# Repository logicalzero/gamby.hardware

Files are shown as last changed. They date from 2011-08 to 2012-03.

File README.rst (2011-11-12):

gamby.hardware README
=====================

This repository contains the EAGLE files for the GAMBY LCD/Game shield for
Arduino.

If anyone is interested in porting the design over to a non-proprietary
format (e.g. gEDA), please contact me! 

Design Notes
------------

* Every Arduino pin has a second pad. These pads conform to a uniform .1" spacing, correcting the .05" offset of the header for digital I/O pins 8-13 and GND/AREF.

* Although it uses the same pins, this design does not use the ATMega's built-in SPI. Since this device does not support bidirectional communication, using the built-in SPI would have wasted a pin; it would have overly complicated the traces as well.

* The traces between all of the 'used' Arduino pins and the second pad have been left uncovered by the bottom soldermask. This is to make it easier to cut the traces should the user want to rewire things -- to make use of the hardware SPI, for example.

* The sound, D-Pad and buttons have pads for headers; the pads are shorted by a thin, uncovered trace. The sound and inputs can be disabled by cutting this trace, then re-enabled by adding a 2-pin header (3 pins, in the case of sound) and a jumper.

Prototypes
----------

The items in the prototypes directory are the versions that were sent for 
short-run fabrication. The pin-out of the first prototype differs from
the new version. The second prototype has a few minor adjustments made
to make it compatible with the fabrication service (0.1" milling bit,
etc.). 

Datasheets
----------

* LCD: Samsung UG09B63-FLGT4AA using `S6B0755 LCD Controller <http://www.alldatasheet.com/datasheet-pdf/pdf/37866/SAMSUNG/S6B0755.html>`__ or compatible (some features unsupported)
* D-Pad: `ALPS SKQAAA010 4-direction switch <http://www.alldatasheet.com/datasheet-pdf/pdf/329112/ALPS/SKQU.html>`__
* Piezo speaker: `TDK PS1240P02BT <http://www.alldatasheet.com/datasheet-pdf/pdf/349367/TDK/PS1720P02.html>`__
* Backlight LEDs: `Dialight 598-8340-107F <http://www.dialight.com/Assets%5CBrochures_And_Catalogs%5CIndication%5CMDEI5981208RT.pdf>`__

Thanks
------

Thanks go out to my fellow Boston dorkbotter, Tim, for reverse engineering
the surplus LCD module.

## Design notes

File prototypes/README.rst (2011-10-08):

prototypes
==========

About
-----

This directory contains the EAGLE source files used to manufacture the GAMBY 
prototype boards. These are here for reference only; the final designs 
improve upon there.

Pin Changes
-----------

Several pins were changed between Prototype 1 and Prototype 2. The new pinout
is expected to be the final version. The GAMBY libraries will be written to use
the new pins; if you are one of the few with a Prototype 1 board you will need
to modify the code or the board itself.

+---------------+-------+-------+
|   Function    |  old  |  new  |
+===============+=======+=======+
| LCD SID       |    8  |    8  |
+---------------+-------+-------+
| LCD SCK       |    9  |   10  |
+---------------+-------+-------+
| LCD RS        |   10  |   11  |
+---------------+-------+-------+
| LCD RESET     |   11  |   12  |
+---------------+-------+-------+
| LCD CS        |   12  |   13  |
+---------------+-------+-------+
+---------------+-------+-------+
| B1/Up         |    7  |    7  |
+---------------+-------+-------+
| B2/Left       |    5  |    6  |
+---------------+-------+-------+
| B3/Right      |    4  |    5  |
+---------------+-------+-------+
| B4/Down       |    2  |    4  |
+---------------+-------+-------+
+---------------+-------+-------+
| Audio         |    3  |    9  |
+---------------+-------+-------+

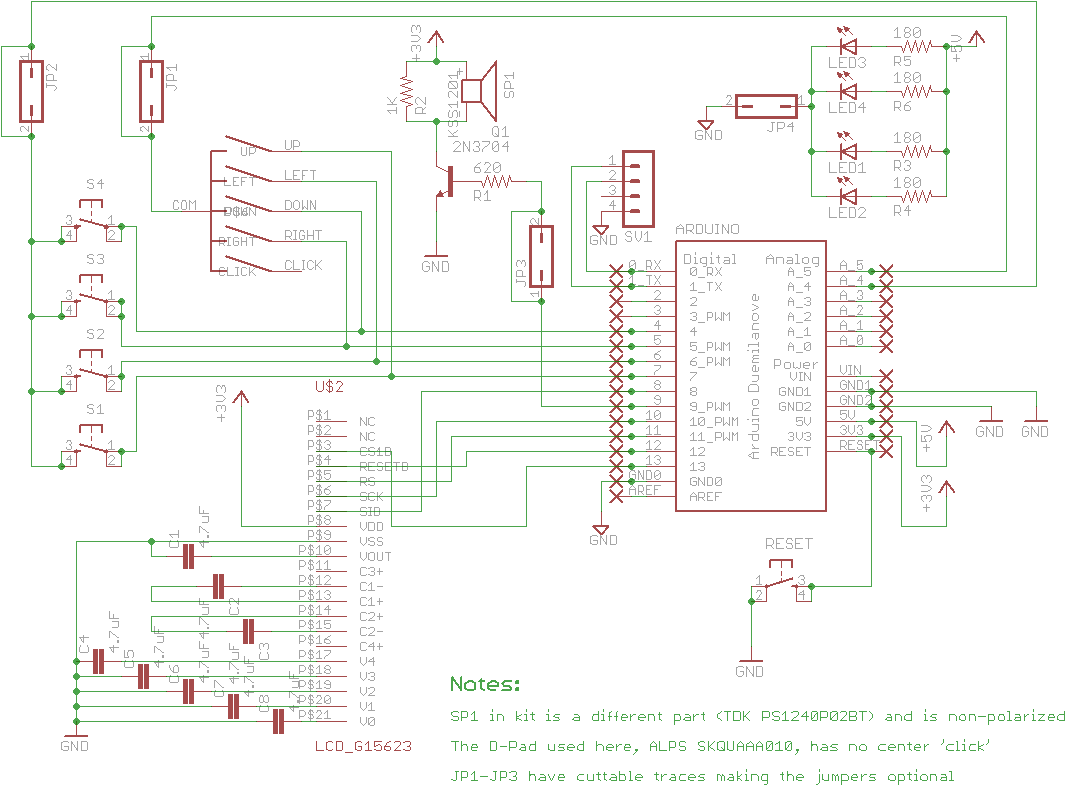
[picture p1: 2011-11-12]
schematic.png

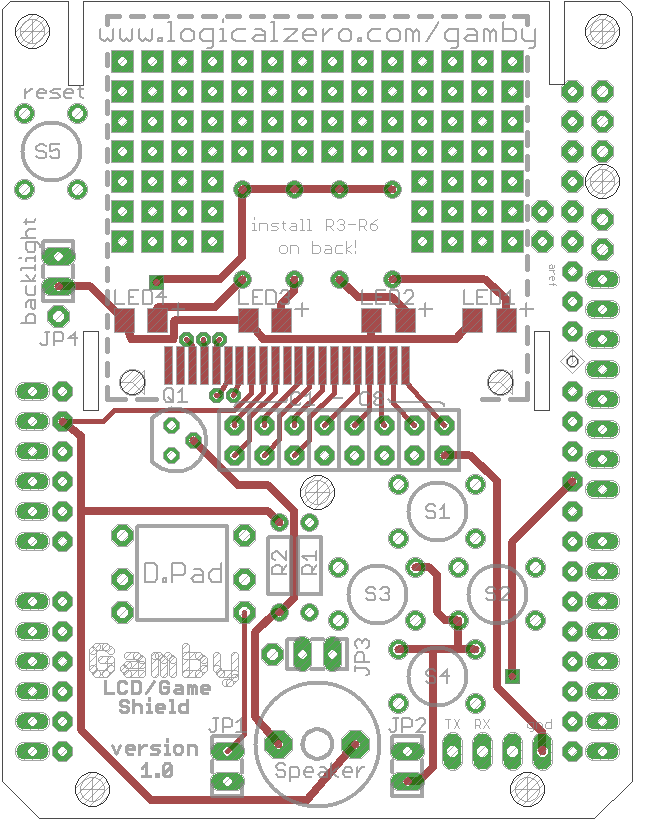
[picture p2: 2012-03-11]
board_top.png

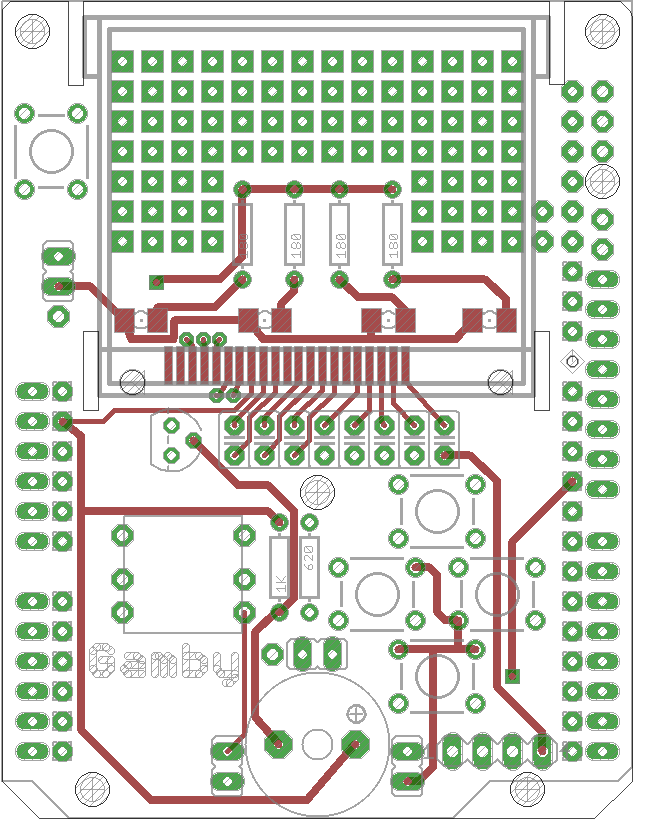
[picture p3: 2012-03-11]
board_top_placement.png

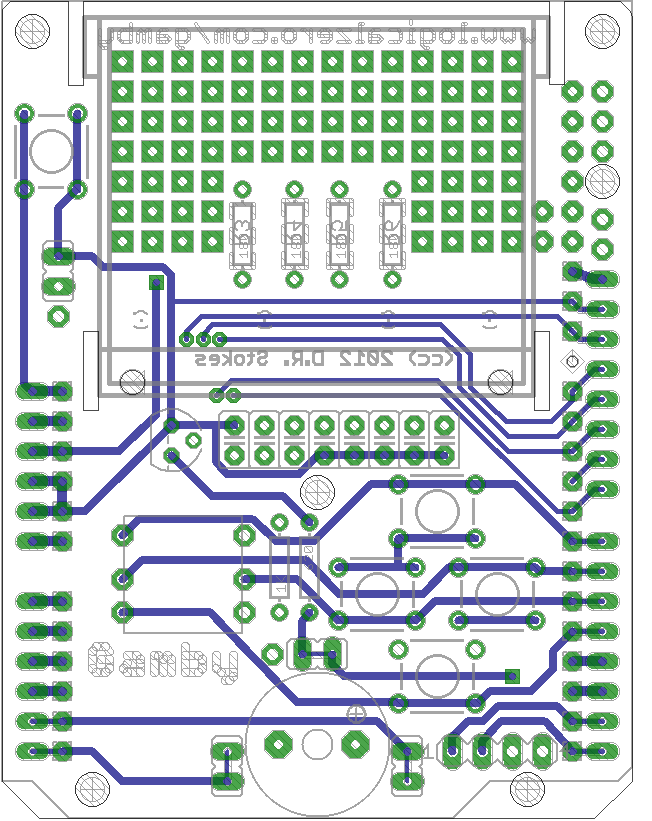
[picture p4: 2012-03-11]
board_bottom_placement.png

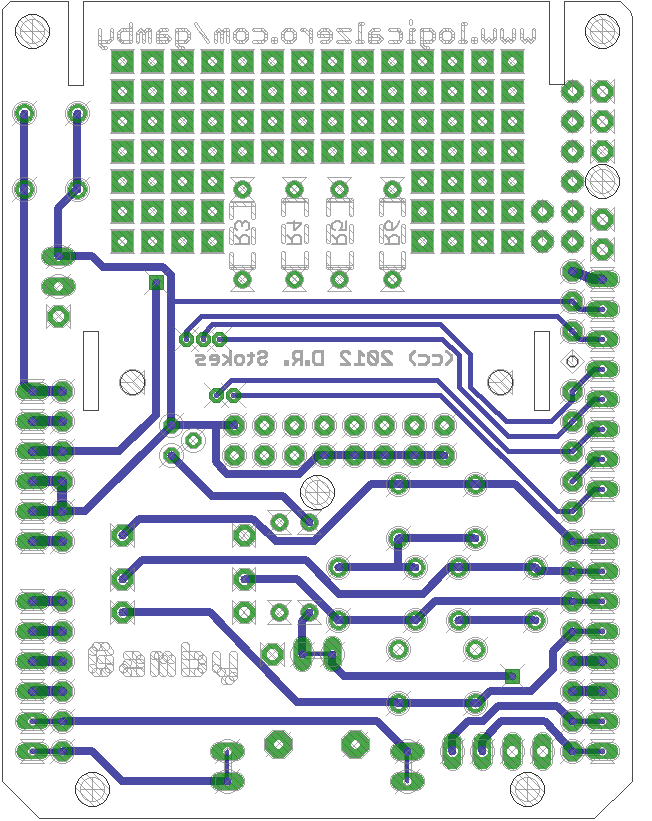
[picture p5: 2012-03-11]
board_bottom.png

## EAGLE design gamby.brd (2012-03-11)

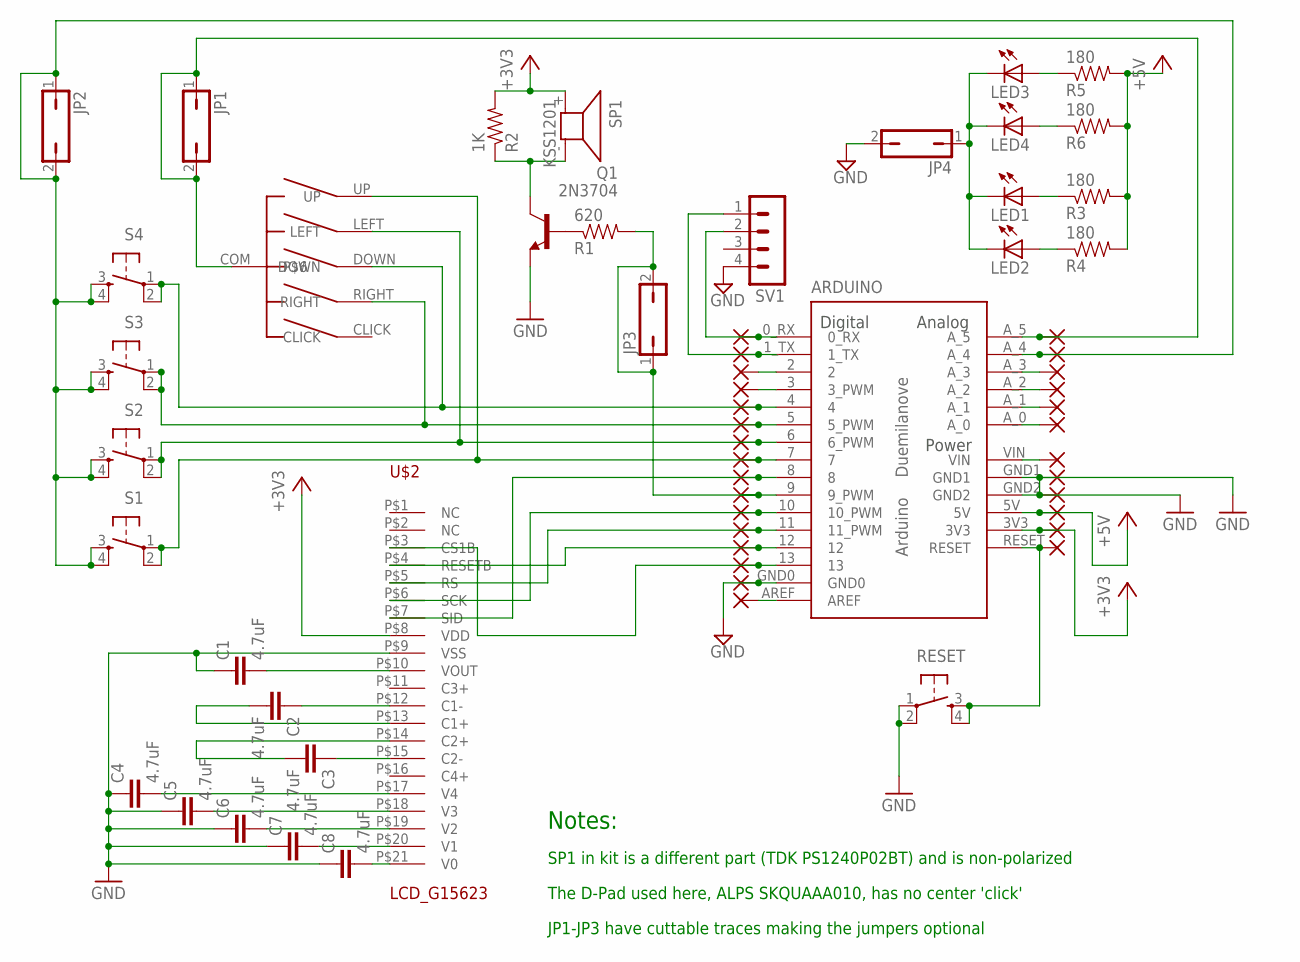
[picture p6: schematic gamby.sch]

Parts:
ARDUINO: ARDUINO-USBLONG_PADS_TEXT; SHIELD
C1, C2, C3, C4, C5, C6, C7, C8: 4.7uF; C2.5-2
JP1, JP2, JP3, JP4: JP1Q; JP1
LED1, LED2, LED3, LED4: LEDSMT1206; 1206
PAD_3V3, PAD_5V: WIREPAD1,6/0,9; 1,6/0,9
PAD_A0, PAD_A1, PAD_A2, PAD_A3, PAD_A4, PAD_A5: WIREPAD1,6/0,9; 1,6/0,9
PAD_AREF: WIREPAD1,6/0,9; 1,6/0,9
PAD_D2, PAD_D3, PAD_D4, PAD_D5, PAD_D6, PAD_D7, PAD_D8, PAD_D9, PAD_D10, PAD_D11, PAD_D12, PAD_D13: WIREPAD1,6/0,9; 1,6/0,9
PAD_GND0, PAD_GND1, PAD_GND2: WIREPAD1,6/0,9; 1,6/0,9
PAD_RESET: WIREPAD1,6/0,9; 1,6/0,9
PAD_RX: WIREPAD1,6/0,9; 1,6/0,9
PAD_TX: WIREPAD1,6/0,9; 1,6/0,9
PAD_VIN: WIREPAD1,6/0,9; 1,6/0,9
Q1: 2N3704; TO92
R1: 620; AXIAL-0.3
R2: 1K; AXIAL-0.3
R3, R4, R5, R6: 180; AXIAL-0.3
RESET: TAC_SWITCHPTH; TACTILE-PTH
S1, S2, S3, S4: TAC_SWITCHPTH; TACTILE-PTH
SP1: KSS1201
SV1: MA04-1
U$2: LCD_G15623
U$3: DEV1; DIP

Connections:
0_RX: ARDUINO.0_RX, PAD_RX.1, SV1.2
1_TX: ARDUINO.1_TX, PAD_TX.1, SV1.1
+3V3: ARDUINO.3V3, PAD_3V3.1, R2.P$2 (2), SP1.+ (1), U$2.P$8 (VDD)
+5V: ARDUINO.5V, PAD_5V.1, R3.P$2 (2), R4.P$2 (2), R5.P$2 (2), R6.P$2 (2)
A0: ARDUINO.A_0, PAD_A0.1
A4_BUTTONS: ARDUINO.A_4, JP2.1, JP2.2, PAD_A4.1, S1.3, S1.4, S2.3, S2.4, S3.3, S3.4, S4.3, S4.4
A5_DPAD: ARDUINO.A_5, JP1.1, JP1.2, PAD_A5.1, U$3.COM
BUTTON_A: ARDUINO.7, PAD_D7.1, S1.1, S1.2, U$3.UP
D2: ARDUINO.4, PAD_D4.1, S4.1, S4.2, U$3.DOWN
D3: ARDUINO.9 (9_PWM), JP3.1, JP3.2, PAD_D9.1, R1.P$2 (2)
D4: ARDUINO.5 (5_PWM), PAD_D5.1, S3.1, S3.2, U$3.RIGHT
D5: ARDUINO.6 (6_PWM), PAD_D6.1, S2.1, S2.2, U$3.LEFT
GND: ARDUINO.GND0, ARDUINO.GND1, ARDUINO.GND2, C1.1, C4.1, C5.1, C6.1, C7.1, C8.1, JP4.2, PAD_GND0.1, PAD_GND1.1, PAD_GND2.1, Q1.3 (E), RESET.1, RESET.2, SV1.4, U$2.P$9 (VSS)
unnamed: ARDUINO.8, PAD_D8.1, U$2.P$7 (SID)
unnamed: ARDUINO.10 (10_PWM), PAD_D10.1, U$2.P$6 (SCK)
unnamed: ARDUINO.11 (11_PWM), PAD_D11.1, U$2.P$5 (RS)
unnamed: ARDUINO.12, PAD_D12.1, U$2.P$4 (RESETB)
unnamed: LED1.A, R3.P$1 (1)
unnamed: LED2.A, R4.P$1 (1)
unnamed: JP4.1, LED1.C, LED2.C, LED3.C, LED4.C
unnamed: LED4.A, R6.P$1 (1)
unnamed: ARDUINO.VIN, PAD_VIN.1
unnamed: Q1.2 (C), R2.P$1 (1), SP1.- (2)
unnamed: Q1.1 (B), R1.P$1 (1)
unnamed: ARDUINO.3 (3_PWM), PAD_D3.1
unnamed: C7.2, U$2.P$20 (V1)
unnamed: C5.2, U$2.P$18 (V3)
unnamed: C8.2, U$2.P$21 (V0)
unnamed: C4.2, U$2.P$17 (V4)
unnamed: ARDUINO.13, PAD_D13.1, U$2.P$3 (CS1B)
unnamed: C6.2, U$2.P$19 (V2)
unnamed: ARDUINO.2, PAD_D2.1
unnamed: C3.1, U$2.P$15 (C2-)
unnamed: C3.2, U$2.P$14 (C2+)
unnamed: C2.2, U$2.P$13 (C1+)
unnamed: C2.1, U$2.P$12 (C1-)
unnamed: ARDUINO.A_1, PAD_A1.1
unnamed: C1.2, U$2.P$10 (VOUT)
unnamed: LED3.A, R5.P$1 (1)
unnamed: ARDUINO.RESET, PAD_RESET.1, RESET.3, RESET.4
unnamed: ARDUINO.A_2, PAD_A2.1
unnamed: ARDUINO.A_3, PAD_A3.1
unnamed: ARDUINO.AREF, PAD_AREF.1

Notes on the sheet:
SP1 in kit is a different part (TDK PS1240P02BT) and is non-polarized
The D-Pad used here, ALPS SKQUAAA010, has no center 'click'
Notes:
JP1-JP3 have cuttable traces making the jumpers optional

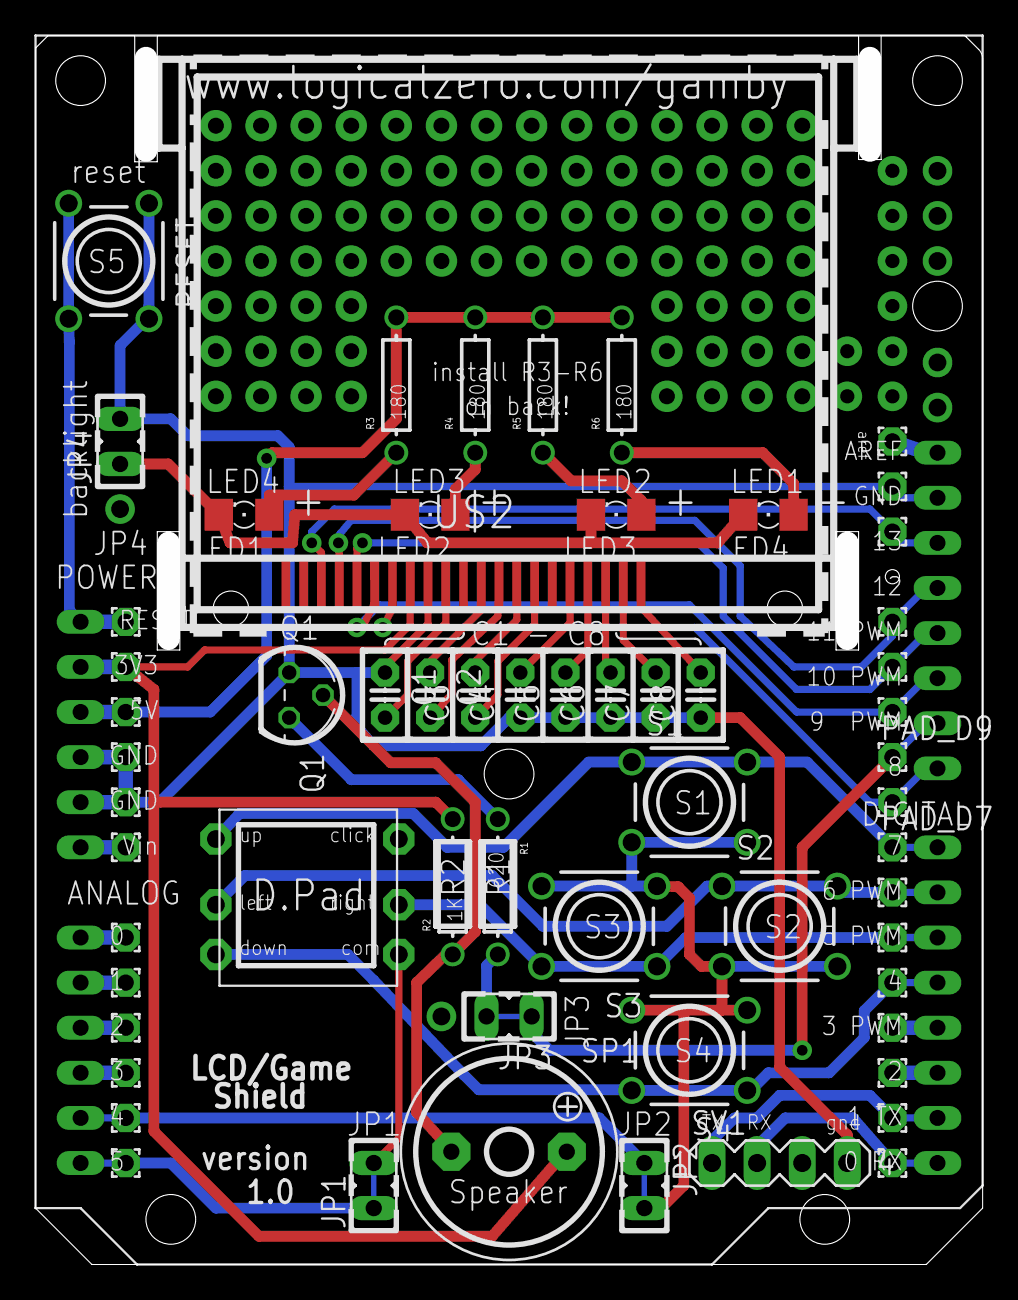
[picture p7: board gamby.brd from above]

Board: 2 copper layers, 53.3 x 69.2 mm, 61 parts (0 on the bottom side), 43 nets.

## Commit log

2011-05-27 First commit of Gamby Eagle files.
    [gamby.brd, gamby.sch]
2011-06-26 Prototype version 2
2011-06-26 Board prototype v2
    [gamby.brd]
2011-07-07 Inner routing moved to outline layer, aligned two holes with Arduino's.
    [gamby.brd]
2011-08-16 Latest revision, plus prototypes (current and first)
    [gamby-prototype1.brd, gamby-prototype1.sch, gamby-prototype2.brd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]
2011-09-11 Made drills for secondary pads larger, changed upper slots to notches, other small tweaks.
    [gamby.brd, gamby.sch]
2011-09-18 Additional small tweaks, added more general-purpose pads.
    [gamby.brd]
2011-10-08 Added README to prototypes subdir documenting pin changes between versions; added .rst extension to main README
2011-10-09 Added cuttable shunts bridging input and sound jumpers, making them entirely optional (and addable later)
    [gamby.brd, gamby.sch]
2011-11-09 Added schematic and board images.
2011-11-12 Added image of schematic, fixed README typo.
2012-02-04 Resaved in new XML-based format.
    [gamby.brd, gamby.sch]
2012-02-17 Moved and added generic pads, enlarged holes over Uno R3 SCL/SDA pins, increased clearances.
    [gamby.brd]
2012-03-04 Re-rendered board images.
2012-03-09 Minor tweaks, mostly cosmetic; added board images with part placement.
    [gamby.brd]
2012-03-11 Shifted secondary pads on 12, 13, AREF to improve clearance; added gerbers.
    [gamby.brd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]
